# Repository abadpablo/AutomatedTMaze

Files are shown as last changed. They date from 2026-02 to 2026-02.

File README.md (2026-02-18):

# AutomatedTMaze

Welcome to the AutomatedTMaze repository !! This is a repository for having all the necessary elements for building an automated TMaze (3D print files and PCB files).

In the Blender files folder you can find the original Blender files in case you want to edit them.

In the Stl files folder you can find the STL files ready for printing in a filament 3D printer machine.

In the Autodesk fusion files you can find the Eagle/Autodesk fusion files. Inside it there is a .zip folder ("Maze.zip") that is the one you want to upload into the PCBway webpage (https://www.pcbway.es/) for fabrication.

## Components

1. Arduino Nano
2. 100 uF capacitor (x7)
3. Servomotor (x5)
4. PCB screw terminals 2 pins (x5)
5. PCB screw terminals 3 pins (x9)
6. PCB screw terminals 4 pins (x1)
7. Mosfet N-terminal IRF520N (x2)
8. IR sensor (x4)

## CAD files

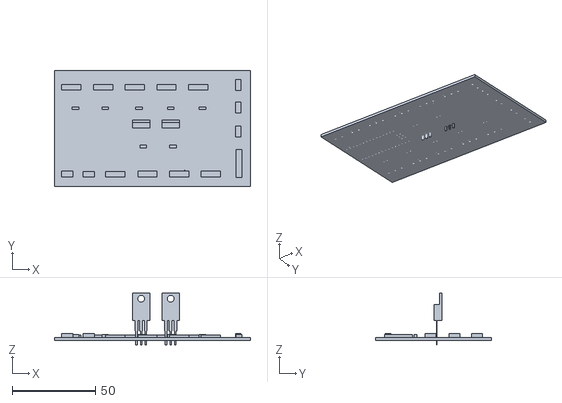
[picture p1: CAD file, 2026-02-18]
Autodesk fusion files/Maze.stl
117.8 x 69.8 x 31.2

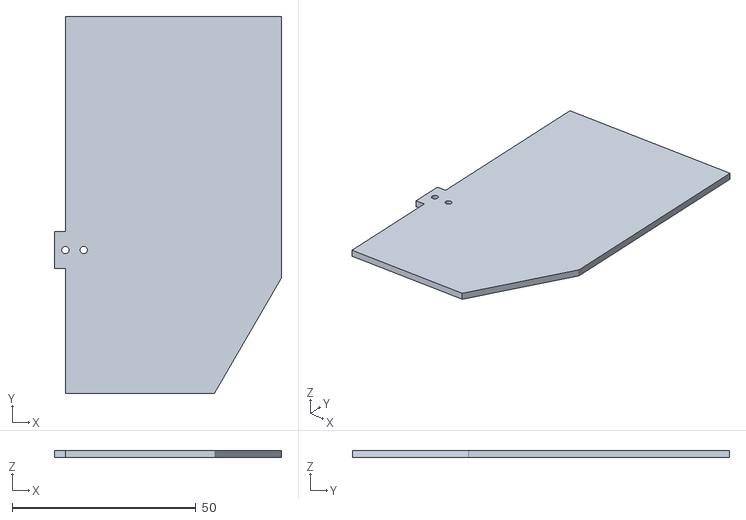
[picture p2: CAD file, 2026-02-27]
Stl files/door.stl
61.8 x 102.5 x 2.00

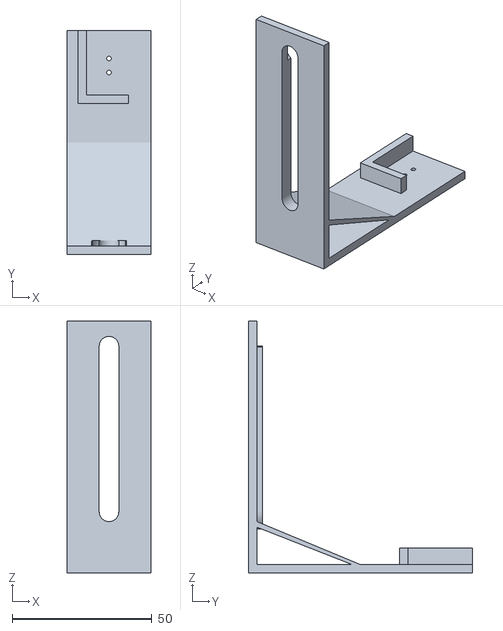
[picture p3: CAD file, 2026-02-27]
Stl files/MotorHolder.stl
30.0 x 80.0 x 90.0

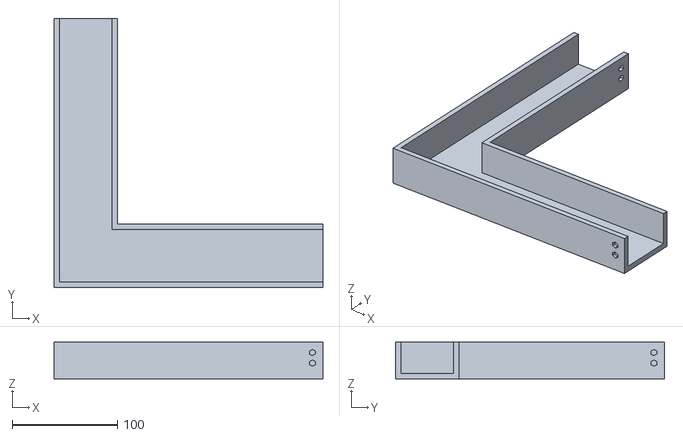
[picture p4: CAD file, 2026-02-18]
Stl files/home_right_arm.stl
255.0 x 255.0 x 35.0

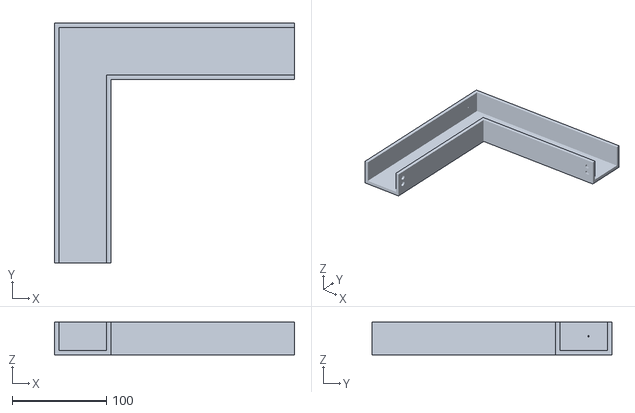
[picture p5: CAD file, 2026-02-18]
Stl files/left_reward_arm.stl
255.0 x 255.0 x 35.0

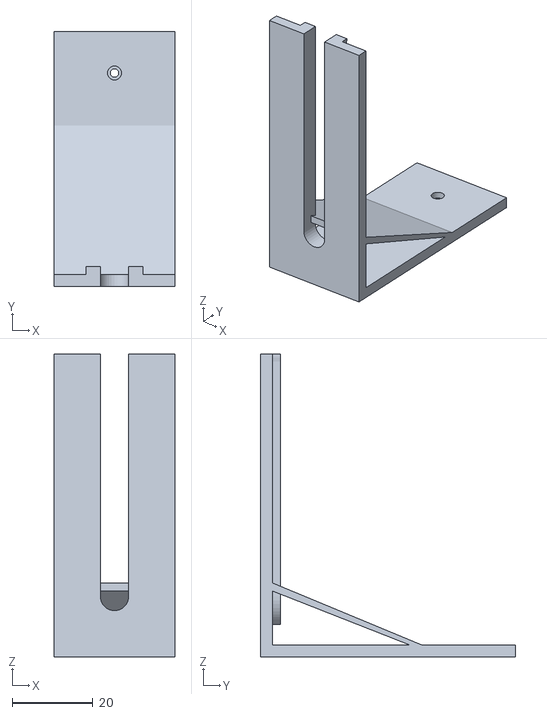
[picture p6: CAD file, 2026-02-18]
Stl files/IR_holder_1.stl
30.0 x 63.3 x 75.2

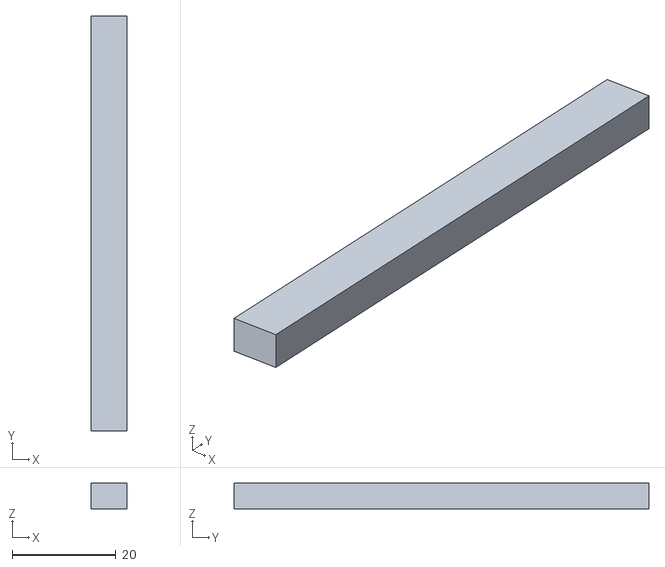
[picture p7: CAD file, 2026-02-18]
Stl files/support_IR_sensor.stl
7.00 x 80.0 x 5.00

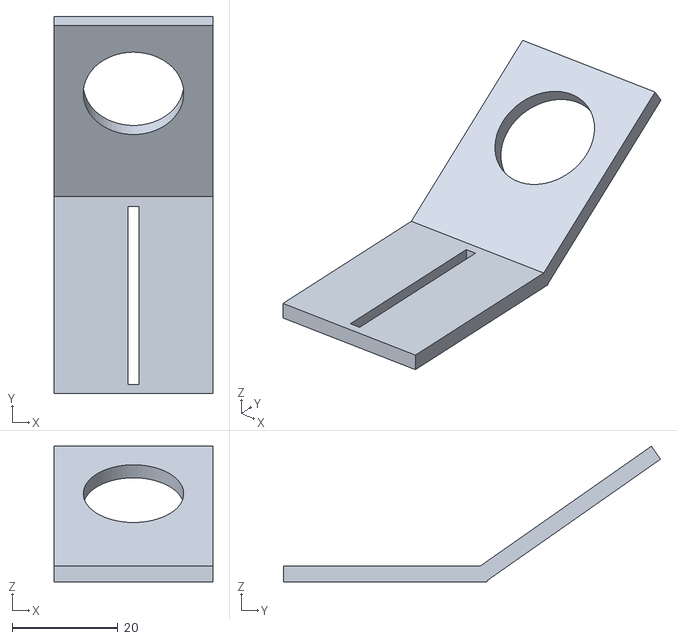
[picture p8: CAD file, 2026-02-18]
Stl files/IR_holder_2.stl
30.0 x 71.2 x 25.6

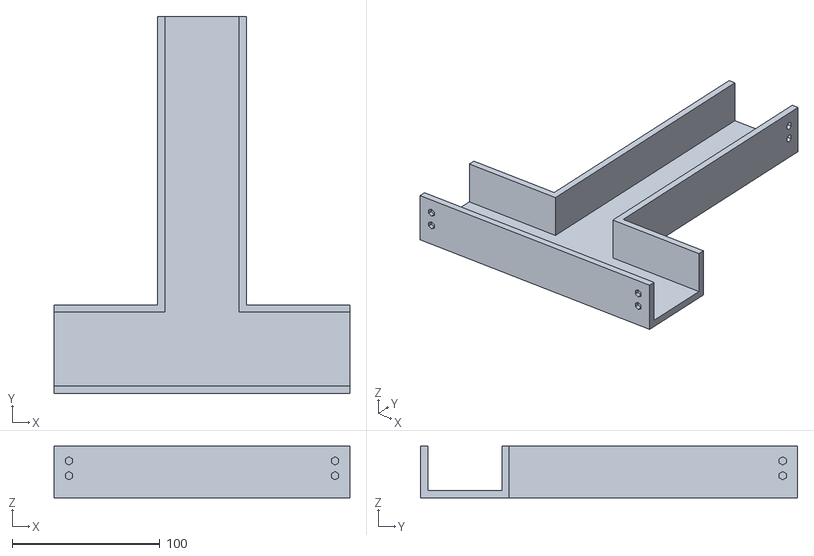
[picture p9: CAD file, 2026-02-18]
Stl files/center_arm_2.stl
200.0 x 255.0 x 35.0

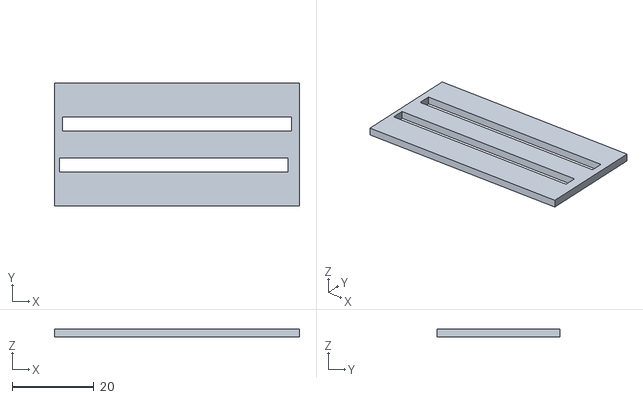
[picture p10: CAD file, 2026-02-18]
Stl files/union_maze.stl
60.0 x 30.0 x 2.00

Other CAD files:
Stl files/right_reward_arm.stl
Autodesk fusion files/Maze.f3z
Blender files/center_arm_1.blend
Blender files/center_arm_2.blend
Blender files/home_left_arm.blend
Blender files/home_right_arm.blend
Blender files/left_reward_arm.blend
Blender files/right_reward_arm.blend
Blender files/support_IR_sensor.blend
Blender files/union_maze.blend

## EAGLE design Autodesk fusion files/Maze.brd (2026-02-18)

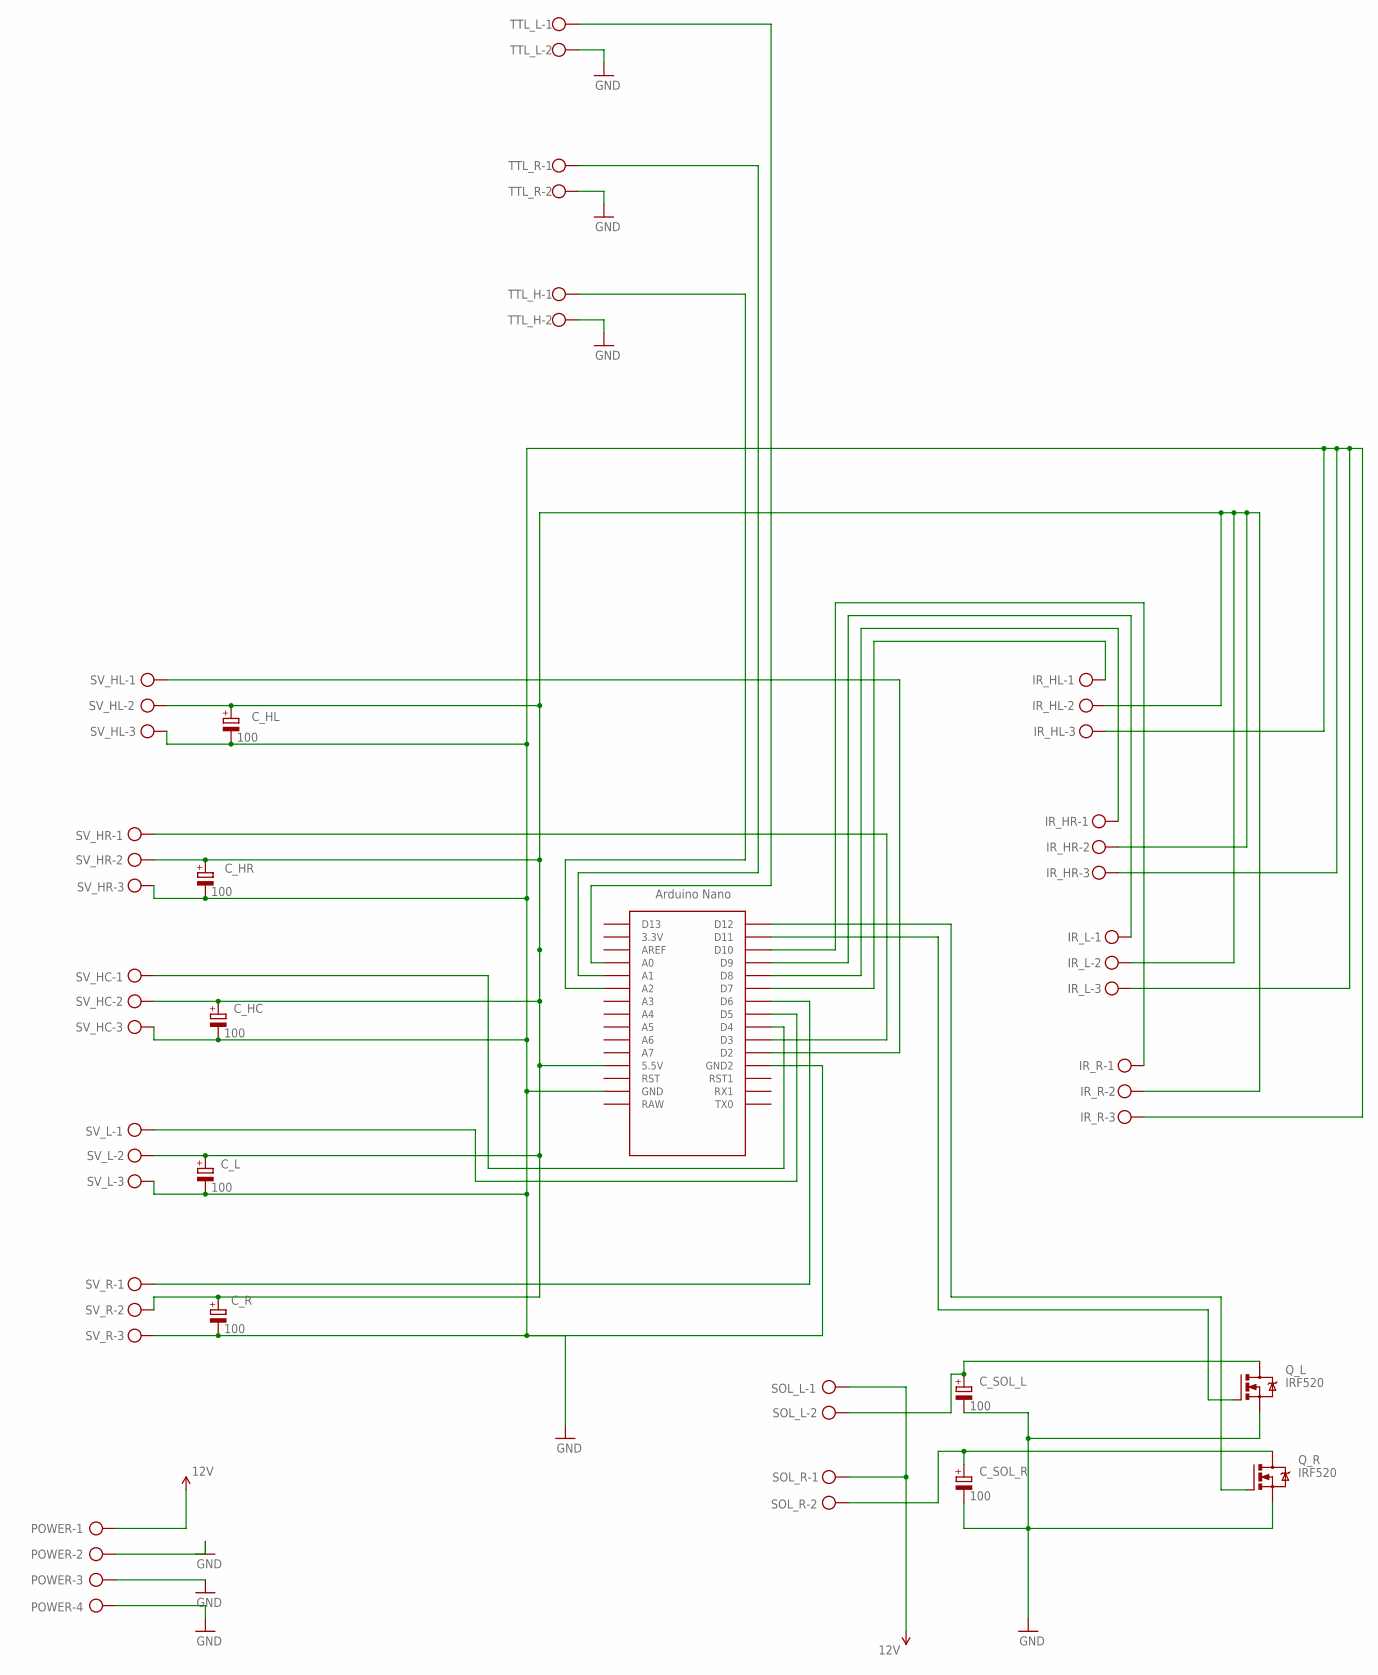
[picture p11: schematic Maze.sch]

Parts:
C_HC: 100; E2,5-6
C_HL: 100; E2,5-6
C_HR: 100; E2,5-6
C_L: 100; E2,5-6
C_R: 100; E2,5-6
C_SOL_L: 100; E2,5-6
C_SOL_R: 100; E2,5-6
IR_HL: W237-103
IR_HR: W237-103
IR_L: W237-103
IR_R: W237-103
POWER: W237-4
Q_L: IRF520; TO220BV
Q_R: IRF520; TO220BV
SOL_L: W237-102
SOL_R: W237-102
SV_HC: W237-103
SV_HL: W237-103
SV_HR: W237-103
SV_L: W237-103
SV_R: W237-103
TTL_H: W237-102
TTL_L: W237-102
TTL_R: W237-102
U$1: NANO

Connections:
12V: POWER.1, SOL_L.1, SOL_R.1
GND: C_HC.-, C_HL.-, C_HR.-, C_L.-, C_R.-, C_SOL_L.-, C_SOL_R.-, IR_HL.3, IR_HR.3, IR_L.3, IR_R.3, POWER.2, POWER.3, POWER.4, Q_L.S, Q_R.S, SV_HC.3, SV_HL.3, SV_HR.3, SV_L.3, SV_R.3, TTL_H.2, TTL_L.2, TTL_R.2, U$1.GND, U$1.GND1 (GND2)
unnamed: SV_HL.1, U$1.D2
unnamed: SV_HC.1, U$1.D4
unnamed: SV_R.1, U$1.D6
unnamed: SV_HR.1, U$1.D3
unnamed: SV_L.1, U$1.D5
unnamed: IR_HL.1, U$1.D7
unnamed: C_HC.+, C_HL.+, C_HR.+, C_L.+, C_R.+, IR_HL.2, IR_HR.2, IR_L.2, IR_R.2, SV_HC.2, SV_HL.2, SV_HR.2, SV_L.2, SV_R.2, U$1.5V (5.5V)
unnamed: IR_HR.1, U$1.D8
unnamed: IR_L.1, U$1.D9
unnamed: IR_R.1, U$1.D10
unnamed: C_SOL_L.+, Q_L.D, SOL_L.2
unnamed: Q_L.G, U$1.D11
unnamed: C_SOL_R.+, Q_R.D, SOL_R.2
unnamed: Q_R.G, U$1.D12
unnamed: TTL_L.1, U$1.A0
unnamed: TTL_R.1, U$1.A1
unnamed: TTL_H.1, U$1.A2

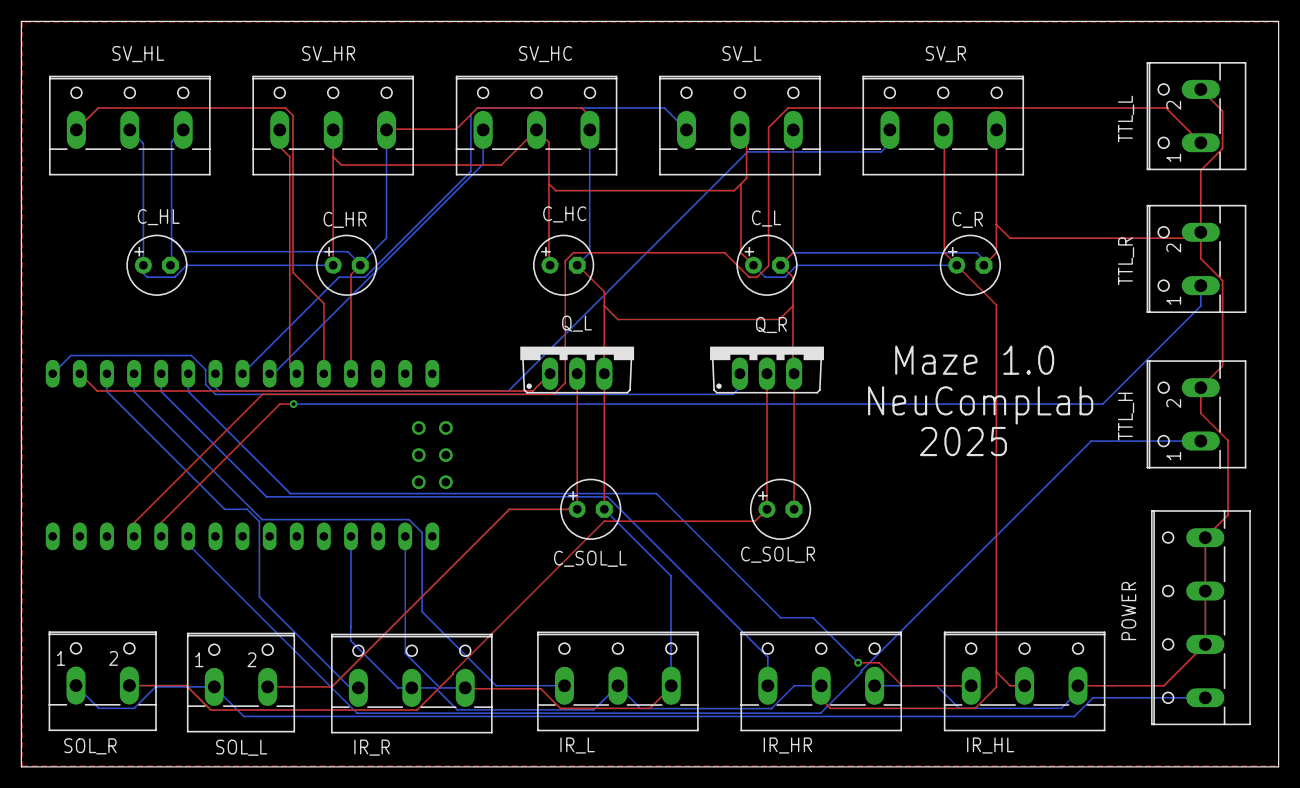
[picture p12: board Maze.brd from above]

Board: 2 copper layers, 117.8 x 69.8 mm, 25 parts (0 on the bottom side), 19 nets.

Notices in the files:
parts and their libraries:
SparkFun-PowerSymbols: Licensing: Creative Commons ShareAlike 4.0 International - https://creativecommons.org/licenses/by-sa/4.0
